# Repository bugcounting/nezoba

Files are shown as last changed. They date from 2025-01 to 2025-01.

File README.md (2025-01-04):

# Nez-Oba: a custom button-only game controller

The Nez-Oba[^1] project provides the schematics of a fully-programmable
all-button wired game controller board, as well as software to program
the controller's behavior to emulate a standard gamepad, and to
reconfigure its button layout.

The controller software works with Nintendo Switch (as a Pro
Controller), as well as with PC/Raspberry PI (as a generic USB
controller). While it can be used, in principle, for any game, it is
primarily intended to play 2D games that require precise button and
D-pad input &mdash; such as platformers.

## Why a custom controller?

Proficiency at 2D platforming games (Super Mario Maker 2, Celeste,
Super Meat Boy, Levelhead, Super Mario Bros. Wonder, Slime-san, Super
One More Jump, ...)  requires being able to precisely enter complex
button and directional inputs. A standard gamepad is not ideal for
this because:[^2]

- It usually has membrane button switches, which provide a suboptimal
  feedback and may not be as precise as mechanical switches.
  
- Its button layout requires to frequently move fingers (especially
  thumbs) from one button to the other. In contrast, an
  all-button/button-only/[hitbox style
  controller](https://ougaming.com/3/7198/a-quick-look-at-the-hitbox-vs-arcade-stick-de)
  minimizes hand and finger movement, and simplifies reliably entering
  complex presses.

There are numerous all-button controllers for PCs, and a few even work
with the Nintendo Switch. In particular, I like the [Junk Food
Arcades' Snack Box
Micro](https://junkfoodarcades.com/collections/snack-box-micro), as
well as [8bitdo's Arcade Stick](https://www.8bitdo.com/arcade-stick/)
[modded](https://www.youtube.com/watch?v=Yn7xL-vFdPc) with
[MyrzArcade's L-shaped
T-Spin](https://www.etsy.com/listing/733030620/t-spin-pcb-only-diy-tetromino-shaped)
(see also [OmniArcade's Odin](https://www.etsy.com/shop/OmniArcade) if
you like the WASD layout). The [Edgeguard keyboard
adapter](https://keyboard.gg/) also looks great. However, none of
these options supports switching between different programmable button
layouts without reconfiguring the board's software; their default
layout is not ideal for games like SMM2; and the distance between
buttons is somewhat wide, which can make repeatedly pressing certain
button combinations unconformable in the long run.

Hence, I went down this rabbit hole starting in the fall of 2021. The
first (and, so far, only) two fully working Nez-Oba game controllers
were completed in March 2022, and I've been using them with gusto ever
since.

After that, I worked on and off to improve the software, develop a
usable web-based GUI for definining the custom mappings, and to
provide detailed documentation. While there are still plenty of things
that could be improved, this is the first public release of the whole
project.[^3]

This is what the Nez-Oba game controller looks like IRL (this is the
version with black case and red linear Kahil low-profile switches):

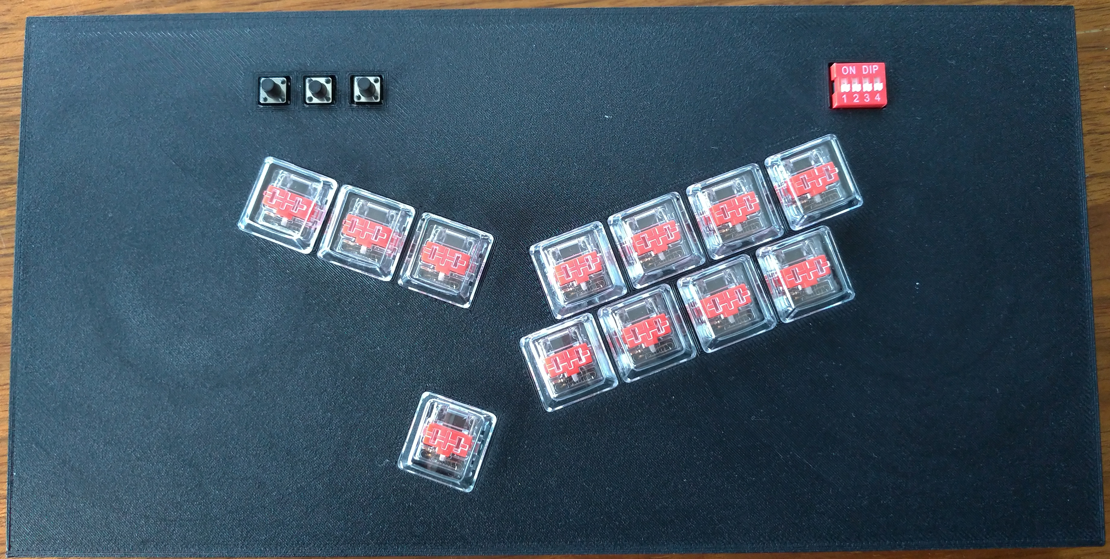
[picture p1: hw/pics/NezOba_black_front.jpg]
the Nez-Oba game controller in black


Its main features:

- Game controller board with twelve mechanical switches (as well as
  three auxiliary switches) and tight, comfortable physical layout.
  
- Fully remappable layout with capacity to store sixteen different
  button-to-key-press mappings.

- Each physical button can map to a combination of up to three
  simultaneous key presses.
  
- Support for turbo functionality (fast repeated key presses).

## Usage

The Nez-Oba projects includes both hardware and software components.

### Build the board

Under [hw/kicad/](/hw/kicad/) you will find:

- PCB schematics of the Nez-Oba board and how to manufacture them

- A list of components that have to be soldered onto the board

You will also need a USB-micro-to-USB-A cable to connect the board's
controller to the Switch or PC.

### Print the case

Under [hw/case/](/hw/case/) you will find 3D models of a case for
the game controller board, which you can 3D-print.

### Install the software

The Nez-Oba software is actually in two parts:

- An Arduino project in C/C++ with the software that runs on the
  board's microcontroller.
  
- A Python project to configure the button-to-key-press mappings that
  the on-board software supports.
  
The Python project is the single entry point to all software, since it
also provides commands to configure, compile, and upload the
microcontroller software.

You install this software as a regular Python project. As usual, it's
recommended that you create a virtual environment to install
dependencies more easily:

```sh
python3 -m venv venv
source vent/bin/activate
python3 -m pip install --upgrade pip
```

Then, there are different options to install the software:

1. Directly from GitHub:

```sh
python3 -m pip install git+https://github.com/bugcounting/nezoba
```

2. From a local copy the Git repository:

```sh
git clone https://github.com/bugcounting/nezoba
cd nezoba
python3 -m pip install .
```

3. From the release wheel:

Download
[/releases/latest/](latest
release wheel `nezoba*.whl`) and install it:

```sh
python3 -m pip install "$NEZOBA.whl"
```

You can also avoid downloading dependencies by using the
[/releases/latest/](`nezoba*.wheels.tgz`):

```sh
tar xf "$NEZOBA.wheels.tgz"
python3 -m pip install wheels/nezoba-*.whl --find-links=./wheels
```

### Use the software

Command `nezoba` is the entry point for using the whole
software. Start with `nezoba -h`.

A common workflow:

1. Have a look at the default button-to-key-presses mappings that I
   defined for 2d platformers: `nezoba show`.
   
2. If you want to define your own mappings, start the GUI with:
    `nezoba gui` (the GUI will appear at
    `http://127.0.0.1:8000/`). Alternatively, there's a simpler CLI
    shell that supports similar functionality: `nezoba cli $MAPPINGS_YAML`.
	
3. Setup the Arduino compiler and libraries with `nezoba setup
   "$SYSTEM_DIR"`, where `$SYSTEM_DIR` is the directory where you want
   to install them.
   
   Alternatively, among the [/releases/latest/](release files) you
   will also find an archive `arduino-cli-4nez.tar.xz` that includes a
   fully setup environment for Linux systems. Unpacking the content of
   that archive under `$SYSTEM_DIR` is an equivalent way of setting up
   your system.
   
4. Deploy the controller's software with your YAML mappings
   `$MAPPINGS`: `nezoba deploy "$SYSTEM_DIR" "$MAPPINGS"`. If you omit
   `$MAPPINGS`, the default mappings for 2d platformers will be
   deployed.
   
The `deploy` command will finally upload to the board. For this to
work, the board has to be plugged in to a USB port of the computer,
and it may have to be reset. See the [troubleshooting
section](/src/README.md#upload-troubleshooting) for a few practical
tips.
   
### Testing/development

If you want to test the installation of the Nez-Oba software, and
possibly change or extend its functionalities:

```sh
# Install the `test` target in editable mode
python3 -m pip install -e .[test]
# Run the Python tests
cd test/nezoba
pytest .
# Run the Arduino software tests
cd test/board
make test
./test
```

[^1]: What does the acronym "Nez-Oba" mean? I'm afraid I don't
    remember :-/

[^2]: Of course, top players make the most out of regular
    controller. On the other hand,
    [Niftski](https://en.wikipedia.org/wiki/Niftski), the
    [top](https://www.youtube.com/watch?v=i_9Hj--VfbY) Mario
    Bros. speedrunner at the time of writing, often uses a mechanical
    keyboard!

[^3]: The dev repository includes nearly 900 commits in 120 days over
    more than 3 years!

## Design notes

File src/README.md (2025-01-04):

# The Nez-Oba software

This directory contains all parts of the Nez-Oba software.

   - Directory [board/](/src/boards/) includes an Arduino project in
     C++, which is the program running on the board and emulates a
     gamepad. The `README` there outlines the code's structure and
     functionality.
	 
   - One of the libraries needed by the the Arduino project have to be
     patched to work with the used hardware. Directory [libs/](/src/libs/)
     includes patch a file to do so.
	 
   - Directory [data/](/src/data/) includes a sample mappings in YAML
     format. This includes several button-to-key-presses mappings that
     are useful to play 2D platformers on the Nintendo Switch or on a
     PC.
	 
   - Directory [nezoba](/src/nezoba/) includes the Python code
     implementing all of the functionality at the user's end,
     including a web-based GUI and a simple command-line interface to
     program the board. The `README`s there outline each package's
     functionality.
	 
   - Directories [src/remapper/](src/remapper/) and
     [test/remapper/](test/remapper/) include the Python
     implementation of a simple interactive shell and its tests. The
     shell can be used to define the button mappings that will be
     uploaded to the controller. See the `README` in those directories
     for details about how the shell is implemented and tested.
	 
   - The current directory's [nez-sw.py](nez-sw.py) is a Python script
     that can setup the Arduino compiler, install all dependencies,
     run the shell to define button mappings, and compile and deploy
     the controller software with the defined button mappings.
	 
The rest of this document describes some low-level details mainly
useful for future portability.

## Environment

This software has been developed and tested on a GNU/Linux Ubuntu
22.04 system. It should work without issues on any other Linux system,
and arguably also on other flavors of Unix. It should also be
adjustable to work on Windows systems without major hassle; however, I
didn't have a chance to test compatibility with that operating system,
and I will probably never care to do it.

## Portable Arduino frameworks
 
The [board's software](/src/board/) targets the Arduino ecosystem, and
was written using the [Arduino
IDE](https://www.arduino.cc/en/software). In order to compile and use
it, you also need to install the Arduino framework.

The main app `nezoba` takes care of installing the framework with all
dependencies under path `$SYSTEM_DIR`:
 
 ```sh
 nezoba setup "$SYSTEM_DIR"
 ```
 
The outcome of successfully running the `setup` command is the
command-line version of a [portable
IDE](https://www.arduino.cc/en/Guide/PortableIDE). This means that if
you save the keep the content of `$SYSTEM_DIR`, you can use it to
recompile and redeploy the controller software at any time in the
future, even after some of the dependencies are no longer available.
 
If you prefer to have the full Arduino IDE (for instance, to debug
changes of functionality in the software), [below I
describe](#portable-arduino-ide-with-dependencies) the manual steps to
do that. The `setup` command does exactly the same things but
automatically and using the CLI version of the Arduino framework;
therefore, the steps detailed below also serve as a documentation of
the behavior of the `setup` command.

In turn, these instructions are derived from the [NSGadget
project](https://github.com/gdsports/NSGadget_HID/tree/master/examples/NSGamepad),
which I found to be the one with the clearest and up-to-date
documentation among the several open-source projects that deal with
Nintendo Gamepad emulation. I adapted and updated the NSGadget's setup
to make it work with the MCP module and with my specific
configuration.

## Upload troubleshooting

When you `deploy` a mappings and the controller software onto a board,
the final upload step is often the most delicate. Here's how to deal
with common issues.

### Plug in the board

Make sure that the board is plugged in to a USB port before uploading.
You should see a port (usually, `/dev/ttyACM0`) pop up after the board
is connected.  There's no need to "activate" the board by pressing a
button.

### Port permissions

If you get an error `Opening port at 1200bps: Permission denied`, it
probably means that your user doesn't have access to the right groups
to access the port:

- Check whether groups `dialout` and `tty` are among the user's
  groups:

```sh
groups
```

- If they are not, add the user to the groups:

```sh
sudo usermod -a -G dialout,tty $USER
```

- This change of groups only works after the next login. To add the
  user to the groups right away:
  
```sh
newgrp tty
newgrp dialout
```

- If all else fails, you can try to change the permissions of the port:

```sh
sudo sudo chmod a+rw /dev/ttyACM0
```
### Resetting the board

After the first upload of the modified firmware, it should also no
longer be needed to reset the board to upload to it. Should you need
to reset the board, double-click on the reset button before launching
the upload. (The reset button is reachable from the little hole in the
back of Nez-Oba's case. After you reset, the led should [go from
purple to
green](https://learn.adafruit.com/adafruit-trinket-m0-circuitpython-arduino/circuitpython)).

## Portable Arduino IDE with dependencies

Here is the list of steps to setup a portable Arduino IDE with all
dependencies to compile and deploy the nez-oba controller software.

   1. Download the Arduino IDE for your computer as a zip file
      `arduino-ide.tar.xz`.
   
      - I used version
        [1.8.19](https://www.arduino.cc/en/Main/OldSoftwareReleases#previous)
        but more [recent versions](https://www.arduino.cc/en/software)
        should also work.
	   
      - The script installs [Arduino CLI
        0.21.0](https://github.com/arduino/arduino-cli/releases).
	   
   2. Install the IDE in portable mode to `$INSTALL_TO`, and launch it.
   
   ```bash
   tar xvf arduino-ide.tar.xz
   mv arduino-ide/ $INSTALL_TO
   cd $INSTALL_TO
   mkdir portable
   ./arduino
   ```
   
   3. Under **File -> Preferences**:

      - Uncheck **Check for updates on startup**
	  
	  - Add
        <https://adafruit.github.io/arduino-board-index/package_adafruit_index.json>
        to **Additional Board Manager URLs** (or follow other
        instructions from [Adafruit's
        documentation](https://learn.adafruit.com/adafruit-metro-m0-express-designed-for-circuitpython/arduino-ide-setup)).
		
   4. Under **Tools -> Board -> Boards Manager**:
   
      - Install **Arduino SAMD Boards** version 1.8.12 (more recent
        versions should still work).
		
	  - Install **Adafruit SAMD Boards** version 1.5.14 (more recent
        versions do not work with the `NSGadget_HID` library we'll use!).
		
   5. Restart the IDE.
   
   6. Download project https://github.com/NicoHood/HID version (tagged release) 
      2.8.3. This is the key library that performs controller
      emulation. This is a very actively maintained project (at the
      time of writing); more recent versions may work, but the patch
      that we'll apply has to be compatible with the changes.
	  
      - Download the project as zip file, and install it in Arduino
        IDE by selecting the zip under **Sketch -> Include Libraries ->
        Add .ZIP library**.
		
      - After installing, download the other project
        https://github.com/gdsports/NSGadget_HID commit
        `dfdcb35a07`. This is an extension of the HID project that
        supports emulation of Nintendo Switch gamepads. (The project
        also has an installation script with Arduino CLI, but here we
        simply get the files that we are going to use.) More recent
        versions may also work, but if the HID API undergoes breaking
        changes we may have to also refactor our controller software.
		
	  - Anyway, after downloading the `NSGadget_HID` project, copy the
        content of directories `src/SingleReport` and `src/HID-APIs`
        to the corresponding directories in the installed HID project
        (at `$INSTALL_TO/portable/sketchbook/libraries/HID/`). This
        should copy 4 files in total, 2 in each directory.
		
      - Edit file
        `$INSTALL_TO/portable/sketchbook/libraries/HID/src/HID-Project.h`
        by adding the following after `#include "SingleReport/SingleGamepad.h"`:
		
		```cpp
		#include "SingleReport/SingleNSGamepad.h"
		```
		
		Equivalently, patch it with file `libs/HID-Project.h.patch`. 
		This modification includes the `NSGadget_HID`'s extension headers 
		into the HID library.
		
   7. Edit the SAMD boards file
      `$INSTALL_TO/portable/packages/adafruit/hardware/samd/1.5.14/boards.txt`
      so that the uploaded image will use vid and pid numbers that
      are recognized as a Nintendo-compatible gamepad:
	  
      - Find the following two lines and comment them out with `#`:
	  
	  ```
	  adafruit_trinket_m0.build.vid=0x239A
      adafruit_trinket_m0.build.pid=0x801E
	  ```
	  
	  - Add the following two lines just below the commented out lines:
	  
	  ```
	  adafruit_trinket_m0.build.vid=0x0F0D
      adafruit_trinket_m0.build.pid=0x00C1
	  ```
	  
   8. That's it! Now the portable Arduino IDE has all the
      dependencies and options needed to compile and install the
      nez-oba controller software. Remember to switch to 
	  **Tools -> Board -> Adafruit SAMD -> Adafruit Trinket M0**
	  before compiling.

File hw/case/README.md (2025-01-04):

# The Nez-Oba game controller case

This directory includes CAD drawings of a case for the Nez-Oba
game controller board.

## 3D printing

The STL files can be sliced and 3D-printed. 

- `case-top-2.stl` and `case-bottom-2.stl` are the latest version of
  the case with wide top and bottom parts. The top part includes ten
  holes to host M3 threaded heat-set brass inserts, so that the bottom
  part can be screwed on to the top one. Once assembled, this case has
  a size of approximately 250x126x16 mm, which can be comfortably
  placed on your lap like a mini-keyboard.
  
- A previous design is available in two versions
  `case-{top,bottom}-wide.stl` and `case-{top,bottom}-narrow.stl`. The
  latter is only 207 mm wide, which means it is printable with most
  common consumer 3D printers (whose printable area is usually below
  210 mm). Another difference is that this variant hosts fewer
  heat-set inserts; as a result, the closed case might still show a
  little gap along the long edge; as a makeshift fix, you can print a
  few copies of `clip.stl` and use them to clamp onto the edge. The
  case remains fully usable, but it's not as nice as the other
  version.
  
Pictures `case_*.jpg` under [hw/pics](/hw/pics/) show the wider case
parts after 3D printing:

- The little hole in the bottom part allows you to reach the reset
  button of the Trinket microcontroller by simply using a pin, without
  having to unscrew the top.
  
- The solid ribs in the bottom part press onto the PCB to ensure that
  it does not move inside the case. They are not strictly needed, but
  they help get a tighter assembly.

I printed these in PETG material through
[Craftcloud](https://craftcloud3d.com/), a hub that dispatches 3D
print orders to providers in different countries.

## CAD sources

There are also fully editable Blender CAD sources (I created them with
Blender 3.6) of the two case design: `case-2.blend` is the latest,
wide design, whereas `case.blend` is the older design in two variants
(wide and narrow).

The overall model is built by combining various components using
Boolean modifiers (union and difference). If you want to modify any
parts of the model, you can find the various components hidden in the
list of objects.

Exporting the Blender model to `stl`format should give you the same
files as described in the [previous section](#3d-printing).

## 2D outlines

In this directory, you can also find other sketches I used to build
the 3D model of the case.

1. `footprints.svg` is a drawing exported from the [PCB
   schematics](/hw/kicad/) of the board, showing the footprints of the
   various components soldered onto the PCB. This is the starting
   point to figure out the design of the case.
   
2. `case-2.svg` is a vertical section of the case with dimension
   lines, showing the various holes and solids that make up the
   interior of the case. (As usual, `case.svg` is the slightly older
   design in two widths.)
   
3. `outlines-2.svg` takes `footprints.svg`, tweaks it, and adds the
   projections of the various elements that are present in the
   internal part of the case. (As usual, `outlines.svg` is the
   slightly older design in two widths.)
   
To create the Blender model, I imported `outlines-2.svg` and extruded
its bi-dimensional components to create three-dimensional shapes
following the dimension lines in `case-2.svg`.

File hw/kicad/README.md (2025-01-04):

# The Nez-Oba controller board

This directory schematics and assembly instructions for the Nez-Oba
game controller board, which can be manufactured as a PCB and then
programmed using the software available [elsewhere](/src/) in this
repository.

The board's design is defined in a [KiCad](https://www.kicad.org/)
(version 5.1.5) project including a schematics, a PCB layout, and
symbol and footprint libraries to make the project self-contained.

## Components

The PCB mounts the following components:

   - An Adafruit [Trinket M0](https://www.adafruit.com/product/3500)
     development board, which runs the controller software.
	 
   - An MCP 23017 port expander, which communicates with the Trinket
     through a clocked serial line. The expander supports 16
     independent digital inputs, which are needed for the many
     buttons of the controller.
	 
   - A piano-type 4-bit DIP switch, which stores the controller's
     configuration number (which, in turn, determines the mapping of
     buttons to gamepad keys).
	 
   - 12 mechanical switches, meant for the 4 directional inputs and 8
     main gamepad buttons.
	 
   - Another 3 switches, meant for the 3 auxiliary gamepad buttons
     (such as *select* and *start*).
	 
The switches are in two groups because the board uses mechanical
switches for the main buttons, and smaller/cheaper tactile buttons for
the auxiliary buttons. However, they all behave the same (and one
could easily change switch type without having to change the
schematics).

## Schematics
	 
The 15 switches are connected each to a separate input of the
expander.  The mapping switch-to-expander makes it easier to lay out
the tracks in the PCB. However, it's essentially immaterial, since any
remapping can be defined via software.

The 4 pins of the DIP switch are connected to the remaining available
digital inputs: 3 of them connect to pins 1, 4, and 2 of the Trinket;
the last one connects to the last input of the expander.

The rest of the connections complete the schematics:

   - All ground pins connect to the Trinket's `GND` pin, which is
     connected to the USB power's ground (hence, it's an output pin
     for the circuit).
	 
   - The expander's three address pins `A0`, `A1`, and `A2` also
     connect to ground. This corresponds to using the [default
     address](https://www.best-microcontroller-projects.com/mcp23017.html)
     0x20. Adding other I2C devices may require to change the address,
     by setting some of these pins to high.
	 
   - The expander's `VDD` and `RESET` pins connect to the Trinket's
     `USB` pin, which draws 5V from the USB power (hence, it's an
     output pin for the circuit).
	 
   - The expander's clock (`SCL`) and data (`SDA`) pins connect to the
     Trinket's clock (pin 2) and data (pin 0) pins (see the [Trinket's
     pinout](https://learn.adafruit.com/adafruit-trinket-m0-circuitpython-arduino/pinouts)). They
     also connect to 5V each [through
     a](https://learn.adafruit.com/using-mcp23008-mcp23017-with-circuitpython/python-circuitpython)
     4.7k Ohm pullup resistor.

## PCB

The symbols used in the schematics are associated with footprints
suitable for the different components used on the PCB. The symbols
also include information about exact product numbers and
manufacturers, so that it should be possible to generate a BOM (bill
of materials) for automated assembly.

The expander has a footprint for a standard DIP packaging with 28 pins
at 2.54mm-pitch, with a form factor of 36x7.8mm.

The 12 mechanical switches mount [Kailh
Choc](https://www.kailhswitch.com/news/kailh-low-profile-mechanical-switches-series-19669171.html)
low-profile mechanical switches. The pin layout is incompatible with
the more common Cherry MX buttons (or other kinds of high-profile
buttons). However, the footprint's size is the same; hence, it should
not be hard to change the design to accommodate Cherry MX switches.

There are *two* symbols for Kailh switches, one for the red (linear)
switches and one for the white (clicky) ones. They are physically and
functionally identical; I created two symbols only to have a way of
storing manufacturer information for both kinds of switches. Indeed,
you can use any other kind of Kailhs, provided they are low profile.

The 3 auxiliary switches mount the cheap 4-pin tactile button
switches, which are very common in cheap electronics starter kits. The
pair of pins on each side of the switch are connected to each other;
clicking the switch connects the pairs on opposing sides. To make this
clear, the PCB connects the two holes on one side of the footprint
with a track. When soldering the switches, make sure to test which
side is connected!

The front layer mounts all switches: main buttons, auxiliary buttons,
and DIP configuration switch. The back layer mounts the control
electronics: Trinket, expander, and the two pullup resistors. This
layout minimizes the height of the top layer, so that the box can
touch the top layer's surface almost everywhere in a stable way.

Most wiring runs on the bottom layer, with only a few short tracks on
the top layer. Filled zones on the top and bottom layers are connected
to ground, which makes for a simple wiring of all ground pins.

The PCB also includes four 4.5 mm diameter mounting holes, at the four
corners of the board.

### Variants of the expander component

A previous version of the controller board (0.1, which was just a
prototype) used an expander mounted on a terminal breakout board
(usually called an CJMCU 2317). This component has the same pinout
(and behavior) as the MCP 23017 expander, but is wired [slightly
differently](https://www.best-microcontroller-projects.com/mcp23017.html):

   - The expander's clock and data pins do not use pullup resistors:
     they just connect to the Trinket.
	 
   - The expander's `RESET` pin connects to 5V through a 10k Ohm
     resistor.

In the attached library, there are also footprints for two models of
terminal breakout boards (of different widths), which should be
mounted using pin headers. The default, however, is to use the MCP
23017 expander without terminal breakout board.

## Changing the board's layout

If you change anything in the schematics (or PCB):

  1. Run the ERC (Electrical Rules Checks) in the schematics layout
     editor (ladybug icon), to make sure they all pass.
 
  2. In the PCB layout editor, click on *Update PCB from schematic*
     (icon to the left of the ladybug icon)
     
	 - Uncheck *Delete extra footprints*, so that the mounting holes
       are not removed.
	   
     - If you didn't change any references (for example, by changing
       it in the footprint editor) you can select *Re-associate
       footprints by reference*. Note that the footprints in library
       `nez-footprint` are set up so that they do not display the
       reference in the PCB view; instead, they display extra text
       that you can customize to reflect the function of each
       component (e.g., each button's default behavior).
	   
     - Click on *Update PCB* and make sure there are no errors.
	   
  3. If you changed anything in the footprints, select *Tools ->
     Update Footprints from Library*. After clicking on *Apply* there
     should be no errors.
	 
  4. Run the DRC (Design Rules Checks) in the PCB layout
     editor (ladybug icon), to make sure they all pass.
	 
	 - Check *Refill all zones*.
	 
	 - I recommend to check both *Report all errors* and *Test tracks
       against filled copper* to perform all checks. It won't take
       long on this simple PCB.
	   
     - Click on *Run DRC* and make sure there are no errors.

In the PCB layout editor, layer *Dwgs.User* is hidden by default. This
includes outlines of all components, which are useful to re-place
footprints after some significant component change.

## Ordering components

The components' symbols also include a link to a page in Digi-Key's
online catalog.

More directly, here are some suggestions about where to buy the
components (from mostly European distributors, but it should not be
hard to find them elsewhere):

   - Any basic 4.7k Ohm resistor should be fine. 5k Ohm ones should
     also work (although I haven't extensively tested them).

   - The 3 auxiliary switches are very common components. Make sure
     you select some with a sufficiently long button cap, so that it
     reaches out of the case.
	 
   - The 4-bit DIP switch is also very common. Check that its
     footprint fits the enclosing case's hole; height should not be an
     issue.
	 
   - Suppliers of components for mechanical keyboards should have the
     Kailh switches, although the Choc models are a bit less widely
     available. (I bought mine from
     [MyKeyboard](https://mykeyboard.eu/): EUR 11 for 20 switches; but
     this seller is [no longer in
     business](https://www.reddit.com/r/MechanicalKeyboards/comments/1ctgniw/mykeyboard_eu_is_bankrupt/). Alternatively,
     there's [42.keebs](https://42keebs.eu/) which is also EU based.)
	 
   - For the expander, look for MCP23017-E/SP components; "E/SP"
     denotes the packaging that the controller uses. As discussed
     [above](#variants-of-the-expander-component), with the default
     layout you just need the bare component, without any mounting
     socket or terminal breakout board (although adding a socket to
     the design should not be hard). Any online electronics shop
     should have them. (I bought mine on Amazon: EUR 4.)
	 
   - Finally, the Trinket M0 should also not be too hard to find. (I
     bought one of mine on Amazon; another one from
     [Distrelec](https://www.distrelec.ch/), which has online stores
     in various countries: CHF 10.)
	 
Altogether, the bare components should cost around EUR 30 (although
you may have to buy some in bulk, using only a few of them).

## PCB manufacturing

To send the PCB layout for manufacturing you can usually either send
the `.kicad-pcb` file or generate plot and drill files. I'll describe
this second way, which is more widely supported (although most PCB
manufacturers also accept CAD files nowadays).

   1. In KiCad's PCB layout editor, click on *Plot* (plotter icon,
      right of the printer icon).
	  
      - *Plot format*: Gerber
	  
	  - Select the following layers: F.Cu, B.Cu (front and back
        copper), F.SilkS, B.SilkS (front and back silk screen),
        F.Mask, B.Mask (front and back solder masks), and Edge.Cuts
        (the perimeter of the board). 
		
	  - Click on *Plot*. This will generate 7 plot files with
        extension `.gbr` (one per layer).
		
	  - In the same window, click on *Generate Drill Files*, and then
        again *Generate Drill File* in the window that opens. This
        will generate 2 drill files with extension `.drl`: one for
        plated through holes (PTH) and one for non-plated through
        holes (NPTH).
	  	
   2. Create a zip file including all 9 generated files (plot and
      drill files).
	   
   3. On the manufacturer's main page, you usually start by an
      approximate size for the PCB. You can measure it in the PCB
      layout editor with the measure distance tool (calipers icon):
      180x104mm should work for the controller board.
	   
   4. Then you upload the zip file with all plot information, and
      select any other options for manufacturing. Default options
      should be fine for this project.
	   
   5. The manufacturer will then perform additional checks to confirm
      they can manufacture the PCB.

I used [EuroCircuits](https://www.eurocircuits.com/) to manufacture my
two Nez-Oba PCBs. They have reasonable prices and deliver high-quality
boards (but YMMV, of course). I payed around EUR 70 for one PCB,
including shipping costs.

## Soldering components

When you assemble the PCB by soldering the components on it, there are
a few things to pay attention to.

   - The Kailh switches' mounting holes are asymmetric, so there's
     only one way that the switches will fit them.
	 
   - The DIP 4-bit switch can be mounted in either directions, but I
     recommend to mount it so that any text on the PCB (especially the
     bit numbers) is readable in the board's "natural" orientation,
     which is the one where the large writing *NEZ-oba* is readable.
	 
   - As explained above, the 4-pin auxiliary button switches have a
     polarity. Check with a multimeter which pairs of pins are wired
     to each other, and then insert one such pair into the pair of
     mounting holes that are also wired with a track on the top layer
     (red line in the PCB layout editor).
	 
   - The MCP23017 also has a polarity. Its [pin
     #1](https://ww1.microchip.com/downloads/en/devicedoc/20001952c.pdf)
     should be marked with a little dot on the DIP packaging; that pin
     goes into the bottom right mounting hole on the back of the PCB,
     which is also marked with a square pad (instead of circular as
     all other mounting holes), as well as with the writing *B0*.
	 
   - Solder header pins to the Trinket, and then solder the other end
     of the pins onto the bottom of the board. Use the writings on the
     board to properly orient the Trinket. In a nutshell, the
     Trinket's top layer (where the tiny reset button is) should face
     away from the PCB's bottom layer, in a way that the Trinket's
     micro USB port is next to the PCB's top edge.
	 
 If you're not sure, use a breadboard to test the components with the
 software, and then assemble them.

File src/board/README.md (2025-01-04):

# The Nez-Oba gamepad controller board's software

This document overviews the structure and logic of the Arduino gamepad
controller board's software, which is included in this directory.

## Configuration numbers

First, a reminder of how users of the board specify which
button-to-key-presses mapping should be used.

The game controller board includes a 4-bit switch in the top-right
corner. The positions of the four microswitches determine the
controller's *configuration number*; each configuration number
corresponds to a different button-to-key-presses mapping.

Thus, a configuration number is an integer in the range from 0 to 15
(included); thus, the controller stores up to 16 different button
mappings.  To select configuration number `N`, move the microswitches
so that they spell out `N` as a four-digit binary number: a
microswitch in the upper position indicates binary digit `1`, and a
microswitch in the lower indicates binary digit `0`. For example,
configuration number `5` (`0101` in binary) is selected when the first
and third microswitches are low, and the second and fourth
microswitches are high.

If you use the Nez-Oba GUI, it wil display the configuration number as
it should appear on the board.

## Main file: `board.ino`

The entry point of the board software is Arduino project file
`board.ino`.  The program is not that long, but it's broken down into
several included files so that it's easier to navigate and modify, and
so that it can be more easily tested.

By default, the `#define DEBUG` definition is commented out, so that
the software is ready for deployment. If you uncomment it, when the
program runs on the board it will print what it's doing in each step
on the `Serial` interface. You can use this to check the buttons
before actually connecting the board to the host. (Printing on
`Serial` doesn't interfere with the controller's functionality, so you
can also use a debug build on the host.)

## File `debug.h`

File `debug.h` is included next.  This defines the macro `debug()`,
which prints its argument on `Serial` (if `TESTING` is not defined) or
on standard output. The offline testing program (in directory `test`)
defines `TESTING` to use the latter; the standard debugging behavior
uses `Serial` as described above.

Macro `debug()` is always defined, instead of being removed by the
preprocessor if `DEBUG` is not defined. This has the advantage of
ensuring that the debugging code remains consistent with the deployed
code (or at least that it can be compiled). Then, we rely on the
optimizing compiler to remove the `debug()` statements (which are
never executed when `DEBUG` is undefined).  This is the reason why
`debug()` is written as a `do ... while` loop: it should make it
easier for the compiler to recognize it as dead code. Indeed, you can
check that the compiled program size in non-debug mode remains the
same, even if we define macro `debug()` as empty.

The other macros `init_time()` and `loop_end()` implement basic
measures of performance. Macro `init_time()` should be called at the
end of the controller's setup to save the absolute time then. Macro
`loop_end()` should be called at the end of each iteration of the main
control loop; it will update and print the average time it took to
complete a control loop.

These macros are meant for online testing (`DEBUG` defined but
`TESTING` undefined); however, they work also during offline testing
to check that they do not interfere with the rest of the control
program.

## File `keys.h`

File `keys.h` defines several constants that identify the various
buttons and keys of the controller.

A **button** is a physical button on the nez-oba.
There are `N_BUTTONS` such buttons, each identified by an integer in the 
range `[0..N_BUTTONS-1]`.

The comment above the definition of `N_BUTTONS` shows how the buttons
are to be numbered in any mapping. It's important that function
`nezoba.remapper.encoding.Exporter.encode` encodes buttons in the same
order. If you need to change this order, you'll have to adjust the
definition of `BUTTONS2CMP` in `globals.h` consistently.

A **key** is an event that can be triggered on the emulated gamepad
(a key press);
there are `N_KEYS` such events in total, 
each identified by an `enum` integer in the range `[0..N_KEYS-1]`.
There are several categories of keys, identified by macro predicates.

- Keys `n` that satisfy `IS_NOOP(n)` correspond to a "no op", used to
  map controller buttons that are disabled.
	 
- Keys `b` that satisfy `IS_BUTTON(b)` correspond to regular gamepad
  buttons, that is everything other than a directional input.
	 
- Keys `d` that satisfy `IS_DP(d)` correspond to 9 D-pad directions:
  up, up right, right, down right, down, down left, left, up left, and
  centered (neutral).
	 
- Keys `l` that satisfy `IS_LS(l)` correspond to 9 left-stick
  directions (the same as the D-pad).

- Keys `r` that satisfy `IS_RS(r)` correspond to 9 right-stick
  directions (the same as the D-pad).
	 
A **mapping** associates each button to up to three keys.
The *current* mapping is stored in three arrays `KEY1`, `KEY2`, and `KEY3`:
`KEY1[b]`, `KEY2[b]`, and `KEY3[b]` are the three key events that
are triggered (simultaneously) when button `b` is pressed.

In most cases, you only want to trigger one key event per
button. Then, just set one mapping slot to the key event, and the
other two slots to `K_NOOP`.

If you want to **turbo** a key event `K`, set the mapping to `-k`.
Turboing a key means that the controller will rapidly toggle pressing
`K` with a small delay. Turbo is only applicable to regular buttons,
not to directional inputs.

Multi-dimensional array `MAPPINGS` combines 16 `3 * N_BUTTONS`-element
arrays, one for each of the 16 remappings that the controller software
supports.  File `remapNN.h` stores remapping number `NN` (numbered
from `00`) as an initializer of a `3 * N_BUTTONS` array, whose
elements are the remapping's key values in the same order as the
button numbering.  Therefore, the elements at indexes `3*b`, `3*b + 1`, 
and `3*b + 2` are the three keys mapped to button `b`. Again,
`nezoba.remapper.encoding.Exporter.encode` produces an encoding 
consistent with this format.

To change a mapping directly, edit the corresponding `remapNN.h`
maintaining this structure. Use `K_NOOP` for each remapping slot that
you don't want to use. In most cases, though, you won't need to edit
these files directly. If you do, though, command `nezoba decode` can
translate the files `remapNN.h` back into an instance of `Mappings`
used by the Python software.

## File `mcp.h`

File `mcp.h` introduces several macros useful to access the MCP unit
using the I2C protocol through library `Wire`. 

An earlier prototype of the nez-oba software used instead (an older
version of) [Adafruit's MCP23017 Arduino
library](https://github.com/adafruit/Adafruit-MCP23017-Arduino-Library)
together with a [debouncing library for
MCPs](https://github.com/cosmikwolf/Bounce2mcp). However, this just
introduced a significant overhead and, worse, a dependency on older
libraries. By rewriting everything using library `Wire` directly, the
current software is faster, simpler (and hence easier to modify) and
with minimal dependencies on legacy software.

An MCP 23017's 16 input/output pins are split into two banks `A` and
`B` of 8 pins each. Therefore, several registers are split into two
byte-size registers, one for each bank `A` and `B`; the 8 bits of a
byte define the state of the 8 pins in a each bank.

Initially, the file defines several register addresses:

- `MCP_ADDRESS` is the MCP's address on the I2C serial bus, when pins
  `A0`, `A1`, and `A2` of the MCP are all connected to ground. When
  using multiple MCP cascading units, one would change this address by
  setting some of those pins to a high value.

- `MCP_IODIRA` and `MCP_IODIRB` are the addresses of the registers
  used to configure the pins as input (value 1) or output (value 0).
	 
- `MCP_GPPUA` and `MCP_GPPUB` are the addresses of the registers use
  to enable the pull-up resistors (value 1) of any input pins.
	 
- `MCP_GPIOA` and `MCP_GPIOB` are the addresses of the registers that
  store the value (low 0, or high 1) of the pins (or set the value for
  pins configured as output).
	 
- `MCP_GPINTENA` and `MCP_GPINTENB` are used to turn on (value 1) or
  off (value 0) interrupt triggers for each pin.
	 
The MCP module has several other registers for functionality that the
nez-oba doesn't use. All addresses are from [version 1.3.0 of
Adafruit's MCP
library](https://github.com/adafruit/Adafruit-MCP23017-Arduino-Library/blob/1.3.0/Adafruit_MCP23017.h),
which was used in an older version of the controller board software. I
found some register addresses used in
[other](http://www.learningaboutelectronics.com/Articles/Read-input-from-an-MCP230xx-IO-port-expander-connected-to-an-arduino.php)
[MCP
guides](http://www.learningaboutelectronics.com/Articles/MCP23017-IO-port-expander-circuit-with-arduino.php)
not to work with the MCP units I have experimented with. If you find
issues with yours, you may want to check the MCP's spec sheet.

Another point to notice is that the nez-oba software still adopts the
pin ids used by Adafruit's MCP23017 library:

| Pin Name | MCP23017 Pin # | Pin ID |
|:---:|:---:|:---:|
| GPA0 | 21 |  0 |
| GPA1 | 22 |  1 |
| GPA2 | 23 |  2 |
| GPA3 | 24 |  3 |
| GPA4 | 25 |  4 |
| GPA5 | 26 |  5 |
| GPA6 | 27 |  6 |
| GPA7 | 28 |  7 |
| GPB0 |  1 |  8 |
| GPB1 |  2 |  9 |
| GPB2 |  3 | 10 |
| GPB3 |  4 | 11 |
| GPB4 |  5 | 12 |
| GPB5 |  6 | 13 |
| GPB6 |  7 | 14 |
| GPB7 |  8 | 15 |

This is really just a legacy of the earlier version of the software,
but switching to a different scheme has no real advantages, and the
number scheme is anyway immaterial.

The following macros in `mcp.h` assume this numbering
scheme. 

- `IS_GPIOA_PIN` and `IS_GPIOB_PIN` determine if their argument is the
  id of a pin in bank `A` or `B`.
	 
- `PIN2REGISTER` evaluates to `MCP_GPIOA` or `MCP_GPIOB` according to
  whether its argument is the id of a pin in bank `A` or `B`.
	 
- `PIN2BITMASK` gives an 8-bit bitmask where all bits are 0 except for
  the one corresponding to the argument pin id (which is set to
  1). For example, `PIN2BITMASK(14)` is `01000000` (`64` in base 10),
  where the 7th bit from the right is `1` since 14 is the id of pin #7
  in bank `B`.
	 
Macro `MCP_WRITE` takes a register address `REGISTER` and a byte-size
`VALUE`, and writes `VALUE` to `REGISTER` using the I2C protocol: it
initiates the transmission, it sends the `REGISTER` address, it sends
the `VALUE` to be written on that register, and it terminates the
transmission.
 
Macro `MCP_READ` takes a register address `REGISTER` and reads a byte
from that register using the I2C protocol: it initiates the
transmission, it sends the `REGISTER` address to be read, it
terminates the transmission, and it sends a request of 1 byte (from
the register that was just selected). After these statements,
executing `Wire.read()` returns the byte read from the MCP unit.

## File `globals.h`

File `globals.h` defines global variables used by the control
software, and includes the necessary libraries.

Constant `TURBO_PERIOD` defines the delay (in milliseconds) between
toggling a button that is turboed. Then `TT` is just a boolean flag
that is toggled every `TURBO_PERIOD` milliseconds; its boolean value
determines if a pressed turboed button should be pressed on the host.
Currently, only a value of turbo period can be selected, corresponding
to 75 Herz. Any different turbo frequency will be treated as 75 Hz by
`nezoba encode`.

Array `BUTTONS2MCP` translates each button number into the id of the
corresponding MCP unit's pin the physical button is attached to. As
mentioned above, pin ids are as in Adafruit's MCP23017 library. The
names in comments correspond to the names that are printed on the PCB
for identification (although they can obviously be remapped to any key
presses). Remember that the order of elements in this array must be
consistent with the button ordering in the `remapNN.h` files.

Constant `DEBOUNCING` defines the debouncing time (in milliseconds).
Constants `P_CFG_N` define the pin number of the four configuration
bits that are defined on the DIP switch. The first three of them are
bits on the Trinket board; the fourth one is a pin on the MCP (just
because there were no more pins available on the Trinket).

Variable `CFG` will store the current configuration number, as an
integer between 0 and 15.

Then all needed libraries are imported. The `#include` are
conditional: when `TESTING` is set (which is used by offline testing),
some library stubs are imported instead.

Several variables of `byte` type (8 bits) are used for communications
with the MCP unit. Variables `GPIOA_state` and `GPIOA_previous` store
the current and previous state of the `A` pins in each iteration of
the control loop. Variables `GPIOB_state` and `GPIOA_previous` serve
the same purpose for the `B` pins.

Finally, `GPIOA_last_debounce_time` and `GPIOB_last_debounce_time`
record the absolute time (in milliseconds since when the controller
was turned on) when the `A` or `B` pins' state was *debounced*, as
we'll describe later. Using `unsigned long` as type ensures that
debouncing can work for up to more than 49 days of continuous
operation. After that, you may have to unplug and plug back in the
controller if it malfunctions :-)

Array `KEYS2PAD` maps each key to a corresponding named constant in
the `NSGamepad` API. Some of these named constants are the same
number, but it doesn't matter since they are supplied to different
methods of the API (in particular, regular buttonsvs D-pad
directions). At the moment, analog sticks are not supported, and hence
there is no mapping of the corresponding keys to analog stick
directions. Adding support for them should not be hard, but I didn't
implement it since I wouldn't be really using it. I may do so in the
future!

## File `setup.h`

File `setup.h` contains the body of Arduino's `setup()` function,
which is executed once when the board boots up.

The setup performs the following steps:

1. It starts the `Wire` library used to access the MCP unit.

2. It sets the four pins reading the four configuration bits (three on
   the Trinket and one on the MCP module) to *input* with *pullup*
   resistor.

3. It reads the four configuration bits, converts them to an integer
   configuration number `CFG`. The configuration first bit is the most
   significant one.
	  
4. Based on the value of `CFG`, it copies the corresponding mapping
   for each button into arrays `KEY1`, `KEY2`, and `KEY3`.
	  
5. It sets `N_BUTTONS` MCP pins to *input* with *pullup* resistor,
   creates a debouncer object for each of them, and stores the objects
   in array `BUTTONS`.
	  
6. It starts the gamepad module.

7. It records the current time at the end of setup (macro
   `init_time()`).

Since this setup is done only once the board is booted up, if you
change the configuration number you have to turn off and on again the
board for it to take effect.

## File `key_handler.h`

File `key_handler.h` contains the definition of macro `HANDLE_KEY()`,
which decodes a button press into presses or directional inputs on the
gamepad. This macro is used in each iteration of the main control loop
described below.

Macro `HANDLE_KEY`'s argument `KEYID` identifies one of the three
remapping arrays `KEY1`, `KEY2`, and `KEY3`. The other argument `B`
identifies the currently pressed button.

The macro first reads the key that `B` maps to in remapping `KEYID`,
and stores the key value into fresh variable `_k`.  If `_k` is negative, it
means that it corresponds to key `-_k` with turbo.  If this is the
case, it sets the `turboed` and `add_turbo_delay` flags, and changes
the sign of `_k` so that it correspond to a valid key.

If key `_k` is a regular button (not a directional input), the macro
presses it on the gamepad by calling function `press()` after
translating `_k` to the corresponding constant in the `NSGamepad` API.

The condition for calling `press()` is also that `!turboed || TT`:

- If `turboed` is false, the button is just pressed.
   
- If `turboed` is true, the button is pressed only in every other
  control loop cycle, as determined by the turbo-toggle flag `TT`.
	 
If key `_k` is a directional input, the macro combines this
directional inputs with the others into variables `dpad_x` and
`dpad_y`. These variables are initialized to `0` in each iteration of
the control loop. Each directional input changes these variables:
right and left correspond to `+1` and `-1` on `dpad_x` respectively;
up and down correspond to `+1` and `-1` on `dpad_y` respectively.

After reading all directional inputs, we want `dpad_x` and `dpad_y` to
be in the integer range `[-1..+1]`. To this end, macro `HANDLE_KEY`
also resets their values if they have exceeded this range. For
example, it may happen that two buttons are both associated with the
same direction *right*. Then, `dpad_x` would be set to `2`, and then
reset to `1` (which unambiguously identifies a right direction).

This logic also performs some basic SOCD cleaning. SOCD (Simultaneous
Opposite Cardinal Directions) is a problem that occurs when two
directional buttons corresponding to incompatible directions are
pressed simultaneously. For example, pressing *left* and *right*
cannot result in a valid directional input. The gamepad's API that we
are using requires a single 8-direction input for the D-pad, so we
have to resolve these possible inconsistencies. Even if the API
allowed SOCD input, it would still be advisable to avoid it, since it
may lead to inconsistent (possibly nondeterministic) behavior in
games. By using coordinates `dpad_x` and `dpad_y`, opposing
directional inputs reset the corresponding direction to `0` (center),
thus taking care of resolving inconsistencies.

## File `main_loop.h`

File `main_loop.h` contains the body of Arduino's `loop()` function,
which is executed in an infinite control loop.

Each iteration of the control loop performs the following steps:

1. It releases all gamepad keys.

2. It complements the turbo-toggle flag `TT`.

3. It goes through all buttons, and checks which have been
   pressed. For each pressed button, it executes macro `HANDLE_KEY`
   for each of the three keys mapped to the button.
	  
4. It sets a D-pad direction based on the horizontal and vertical
   coordinates `dpad_x` and `dpad_y`.
	  
5. If a key was turboed, it adds a delay.

6. It commits all presses to the gamepad module.

7. It computes and displays the average time to complete a loop
   iteration (macro `loop_end()`).

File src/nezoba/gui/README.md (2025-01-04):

# Package `nezoba.gui`

Package `nezoba.gui` offers an implementation of a web-based GUI,
which supports visual inspection and editing of button-to-key-presses
mappings (defined in package `nezoba.remapper`).

The implementation uses the JustPy web framework. In the end, I had to
extend several components and features of the framework to fit my
needs. Most important, I modified the `justpy.Svg` component to be
able to use parts of an SVG image as clickable and dynamically
editable GUI buttons. Since I didn't want to distribute my own fork of
JustPy, I ended up doing some fairly heavy monkey patching, mostly in
module `utils` described below.

## Module `gui`

This module sets up the GUI as `justpy.WebPage`. The GUI's layout
includes several panes, each either a regular `Div` or a specialized
component defined in module `panes`.

The main wepage uses a [favicon](imgs/nez-oba-favicon.ico), which can
be generated from [this SVG](imgs/nez-oba-favicon.svg) using an
[online converter](https://favicon.io/favicon-converter/).

## Module `panes`

This module includes several specialized HTML components used by the
GUI:

- `Header` is the page's header banner, with the name and number of
  the current mapping.
  
- `Controller` is the page's left main pane, which displays a stylized
  image of the Nez-Oba controller board, whose buttons can be clicked
  to associate a key press with each of them.
  
- `PressList` is used in the page's right main pane, which displays
  all the presses associated with the currently selected button. Each
  press is displayed as an instance of `PressBox`, which shows all the
  information about the press (e.g., if it's turboed) and allows the
  user to edit it.
  
- `Info` is the page's left bottom pane, which shows a description and
  the platform used by the currently displayed mapping.
  
- `Menu` is the page's right bottom pane, with buttons to load/save
  the mappings, create a new mapping, switch between mappings, and so
  on. 

As noted elsewhere, sometimes this module's documentation refers to a
mapping (e.g., the currently selected mapping) as a *configuration*
(e.g., the current configuration). A configuration is often associated
with its index (*configuration number*) in the list of mappings in the
menu.

## Module `widgets`

This module includes other HTML components, which are used as building
blocks by some of the `panes`.

- `OnOffComponent` and `HideShowComponent` are SVG components that can
  be displayed or hidden dynamically.
  
- `InOutButton` is an SVG component that can display text on it (this
  is the *out* part), can be activated by clicking on it and
  deactivated by clicking again (this is the *in* part).
  
- `HoverHighlight` is a way of explicitly highlighting an SVG
  component's background when the mouse hover over it.
  
- `LabelContent` is a `div` component organized as vertically stacked
  subcomponents, each consisting of a label and some content.
  
- `ButtonRange` is a `div` component that displays a range of buttons.

- `SelectOptions` is a `select` component that reacts to changes in the
  model.
  
- `NamedLink` is an `a` link component that displays the URL in the
  model.
  
- `IconButton` is an HTML button component that displays text and/or
  icons on its face.

## Modules `model` and `views`

One of the main overhauls of JustPy is its support for model-based
dynamic components. In JustPy, a component's model is a way of
associating the component's state to the dynamic value of an attribute
(called the *model* of the component). In JustPy, the model[^1] is usually
of type string or integer. In the Nez-Oba GUI, this capability is
substantially extended to accommodate complex model types.

Class `State` encapsulates all the information that characterizes the
GUI's overall state: all mappings, the currently selected mapping, any
save files, and so on.

A component does not directly access the whole state. Instead, a
different `View` encapsulates the whole state and only leaks
information that is needed for a particular purpose. Precisely, `View`
has a single public member `value`, implemented as a property, which
can be read and, possibly, written (depending on whether the component
accessing that view is allowed to change the state).

JustPy's components are equipped with methods `get_model` and
`set_model` to respectively read and write the current model value
linked to that component. Module `model` redefines these methods in a
way that they work on views by default. 

Module `views` includes the actual subclasses of `View` that are used
by GUI components.

## Module `utils`

This module is where most of the dirty work of adapting JustPy's
functionality to our needs is done. Here, I will just describe the
main functions.

- `instrument_component_class` equips an existing JustPy component
  class with all of the extra functionality implemented in this
  project. In particular, it replaces the original `get_model` and
  `set_model` with their extensions defined in `model`.
  
- `filter_by_attribute` provides a way of searching through the
  subcomponents of an HTML component (usually, an SVG) for elements
  with certain attribute values. This is mainly used to display and
  dynamically modify the SVG of the Nez-Oba game controller board as a
  collection of clickable GUI buttons.
  
- Similarly, `by_layer_spec` navigates an SVG not by attribute values
  but according to its hierarchical tree structure. Other functions
  used this in combinatino with `replace`, which supports
  modifications of some parts of a tree structure.
  
- `add_styles` provides a more flexible way of adding CSS styles or
  Tailwind classes to an HTML component in JustPy. This function is
  needed because the version of JustPy that was available when I
  developed Nez-Oba only had support for older versions of Tailwind;
  hence, I had to manually implement some style changes that would
  have been possible with more recent version of Tailwind.
  
- `pack_text` resizes multiple lines of text so that they can be
  displayed to fit (more or less) nicely a bounding box.

- `wrap` provides another kind of monkey patching, one that is used
  directly in the definition of some panes. Precisely, it can turn an
  SVG component into an instance of `InOutButton` or `OnOffComponent`.

[^1]: Pet peeve: JustPy documentation's and terminology occasionally
    uses "model" to refer indifferently to the model *value* (the
    current value of the component's state) and to the *model type*
    (the range of values that the component's state spans). I tried to
    be more rigorous with the terminology, but no takesies-backsies
    :-).

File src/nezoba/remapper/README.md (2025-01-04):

# Package `nezoba.remapper`

Package `nezoba.remapper` provides the main abstractions to define
button-to-key-presses mappings. They are deliberately more general
than what is strictly supported by the Nez-Oba controller board's
software at the moment, so that they may be usable also with future
extensions of the hardware and its software.

## Buttons: module `buttons`

A `Button` instance represents a physical button on the game
controller that can be pressed or depressed. Each button is uniquely
identified by an integer `identifier`.

Class `Buttons` models a collection of buttons, with the convention
that the `k`th button in an instance of `Buttons` is a `Button` with
`identifier == k`.

This usage of identifiers is also relied upon to map buttons to
physical buttons on the Nez-Oba PCB: a comment in
[keys.h](/src/board/keys.h) includes a simple diagram that illustrates
how the 15 clickable buttons on the Nez-Oba board are numbered.

Correspondingly, module `buttons` includes constant `NEZOBA_BUTTONS`,
which is an instance of `Buttons` with all buttons available on the
Nez-Oba board.

## Keys: module `keys`

A `Key` instance represents a possible logical output of a controller,
signaling to the game that a certain key has been pressed. Each key is
uniquely identified by an integer `identifier`, as well as by a unique
name `key`. 

Class `Keys` models a collection of keys. The order of keys in an
instance of `Keys` is immaterial since the keys can be indexed by
`identifier` or by name `key`.

Module `keys` also includes constant `STANDARD_KEYS`, which includes
all keys available on a standard gamepad. Currently, the Nez-Oba
board's software does not support left stick and right
joystick/thumbstick events, whereas all other keys should be
available.

Adding support for the joysticks should not be hard, given that the
Arduino gamepad libraries already support them.

## Combos: module `combos`

A `Combo` instance represents a certain combination of keys. At the
moment, there are two kinds of combos:

- A `Press` represents the pressing of a single key. The press may be
  *turboed* (the key is repeatedly pressed and depressed as long as
  the triggering button is pressed) or *held* (the key is held until
  the triggering button is pressed). Currently, the Nez-Oba controller
  board only supports turbo with frequency of 75 Herz, and does not
  support `hold` presses.
  
- An `And` represents several simultaneous `Press`es. Currently, the
  Nez-Oba controller board only supports up to three simultaneous
  presses.

## Mappings: module `mappings`

A `Mapping` instance represents a `Button` → `Combo` mapping. It is
built around Python dictionaries.

Class `Mappings` models a collection of mappings, all with the same
domain (an instance of `Buttons`) and with codomains with the same
keys used in `Combo`s (an instance of `Keys`).

Throughout this project, sometimes an instance of `Mappings` is also
referred to as a collection of *configurations*, where each
configuration corresponds to an instance of `Mapping`.

## Namings: module `namings`

Module `namings` provides wrappers around classes `Key`, `Keys`, and
`Mappings` that add associate platform-specific *names* to keys.

For example, the same gamepad key that is called `A` on a Nintendo Pro
Controller is called `B` on a PC/XBox controller.

Module `namings` also includes constant `NS_KEYS` and `PC_KEYS`, which
includes all `keys.STANDARD_KEYS` with their names on a Nintendo
Switch gamepad and on a PC/Raspberry Pi controller, respectively.

## Serialization: module `serialization`

Module `serialization` provides functions to serialize/deserialize an
instance of `Mappings` to/from a YAML file.

Functions `to_yaml` and `from_yaml` are the two main entry points for
using this module.

## Encoding and decoding: module `encoding`

Module `serialization` provides means to convert a `Mapping` to the
format used by the Nez-Oba board's software (that is, a C array
format). This conversion is called *encoding* and is provided by
`Encoder.encode`.

Class `Encoder` also provides the reverse conversion, from a C array
format back to an instance of `Mapping`, called *decoding* and
provided by `Encoder.decode`.

Finally, `Encoder.show` formats a `Mapping` instance as a string that
mimicks the controller board's actual physical layout and is human
readable.

The rest of the software does not use class `Encoder` directly but
through class `Exporter`, which handles encoding and decoding through
files.

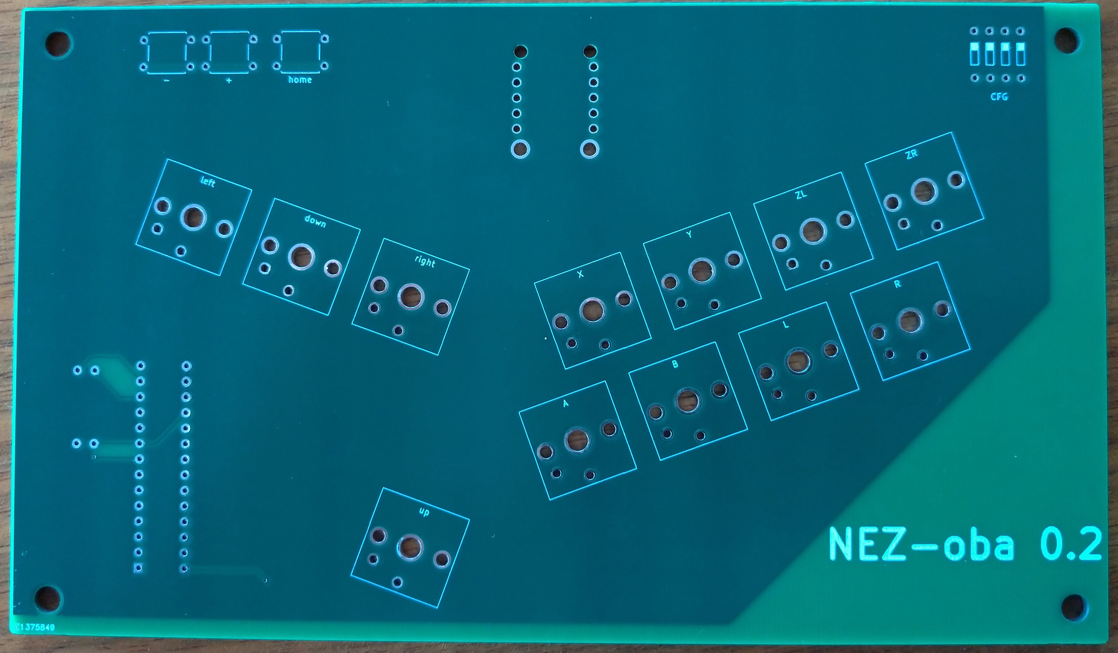
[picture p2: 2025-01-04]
hw/pics/PCB_front.jpg

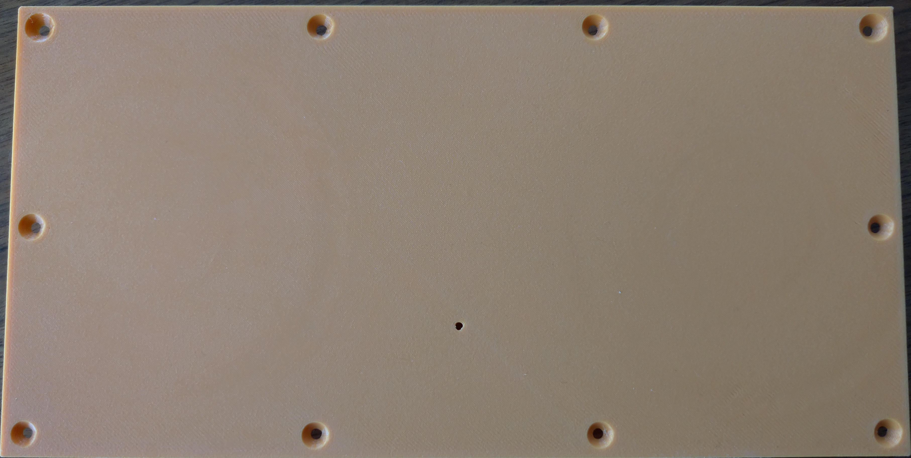
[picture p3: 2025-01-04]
hw/pics/case_orange_bottom_outside.jpg

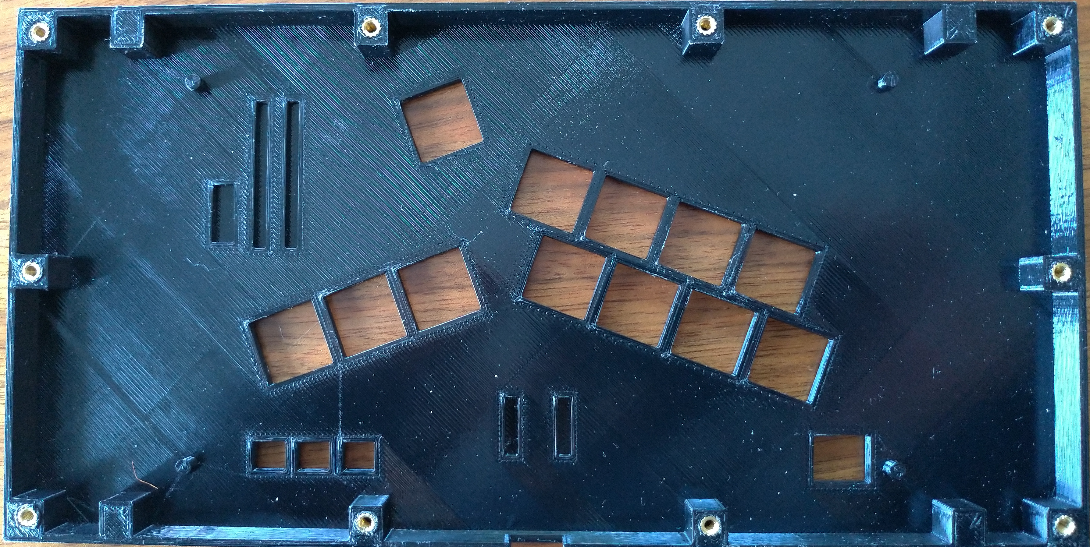
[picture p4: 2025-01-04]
hw/pics/case_black_top_inside.jpg

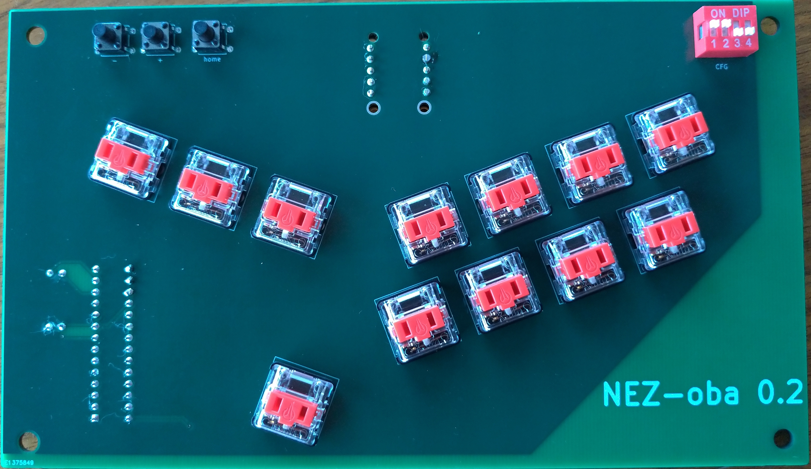
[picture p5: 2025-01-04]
hw/pics/board_front.jpg

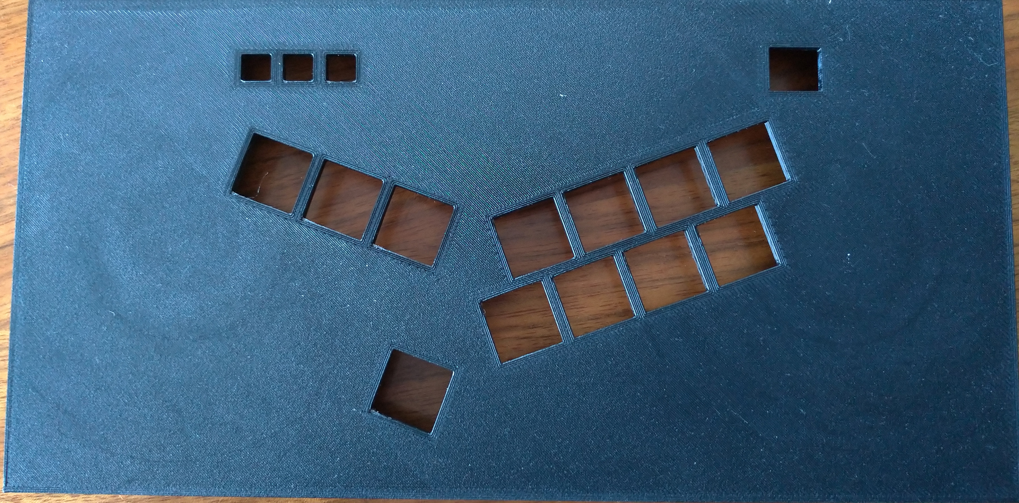
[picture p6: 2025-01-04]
hw/pics/case_black_top_outside.jpg

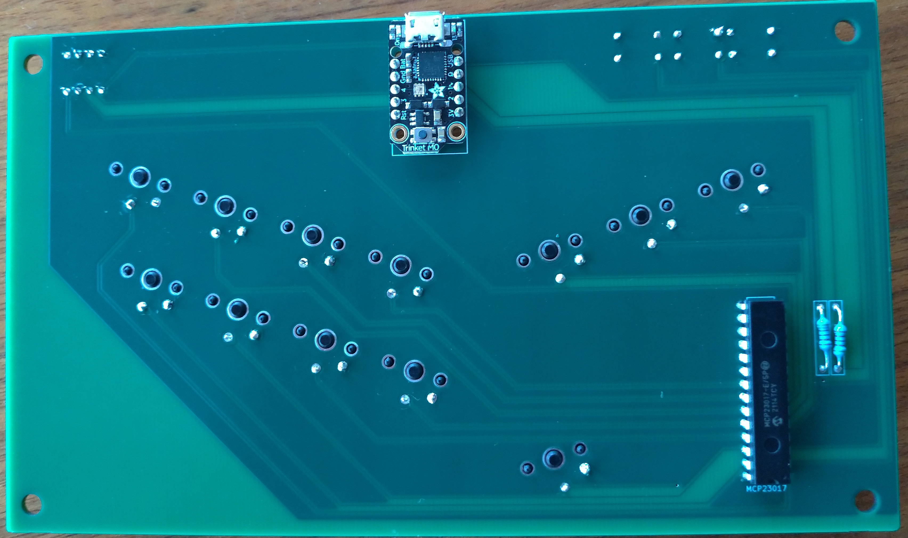
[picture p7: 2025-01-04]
hw/pics/board_back.jpg

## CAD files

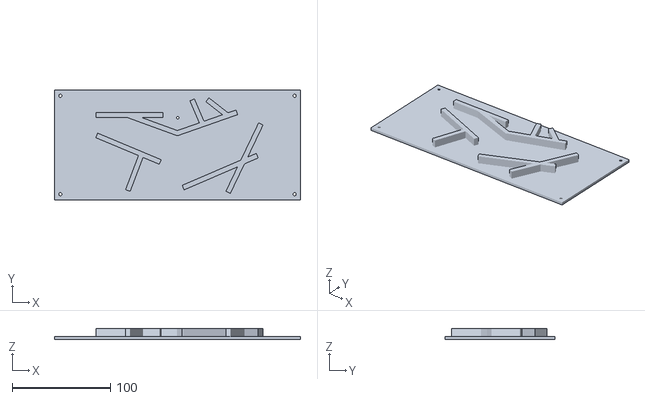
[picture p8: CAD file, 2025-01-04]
hw/case/case-bottom-wide.stl
250.0 x 112.0 x 11.2

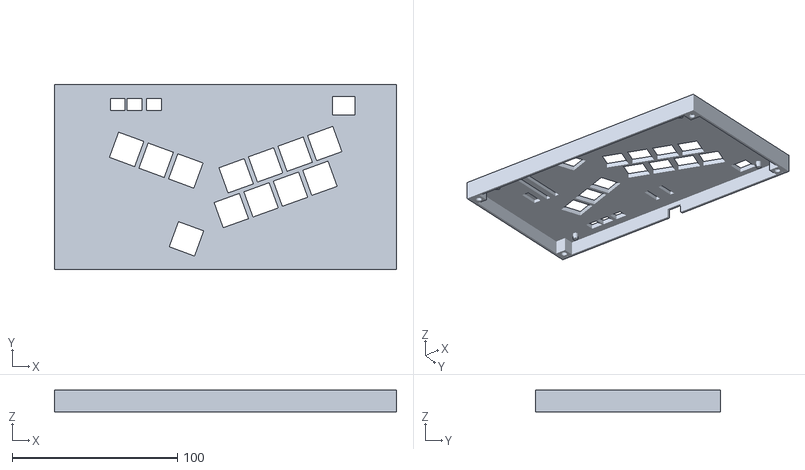
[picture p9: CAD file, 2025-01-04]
hw/case/case-top-narrow.stl
207.0 x 112.0 x 13.3

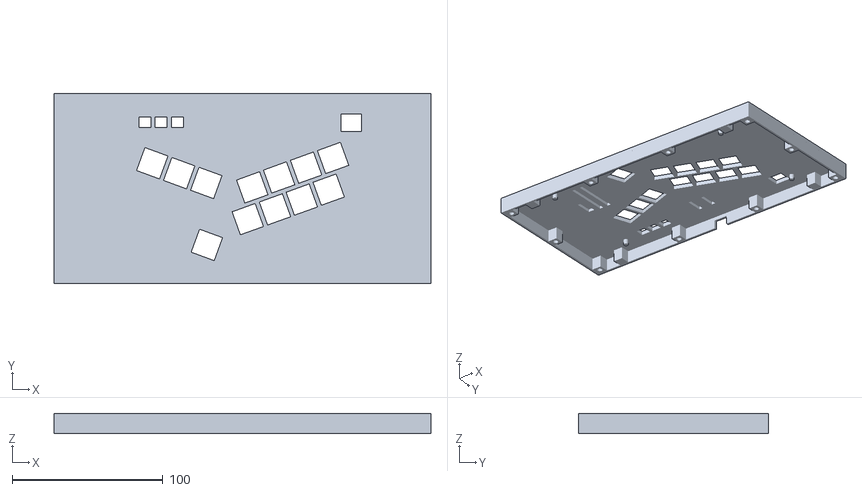
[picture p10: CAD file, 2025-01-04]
hw/case/case-top-2.stl
250.0 x 126.0 x 13.3

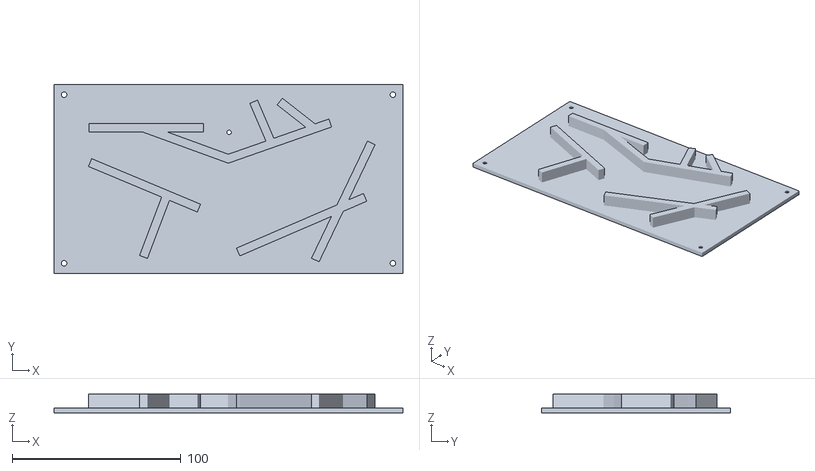
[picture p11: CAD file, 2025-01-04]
hw/case/case-bottom-narrow.stl
207.0 x 112.0 x 11.2

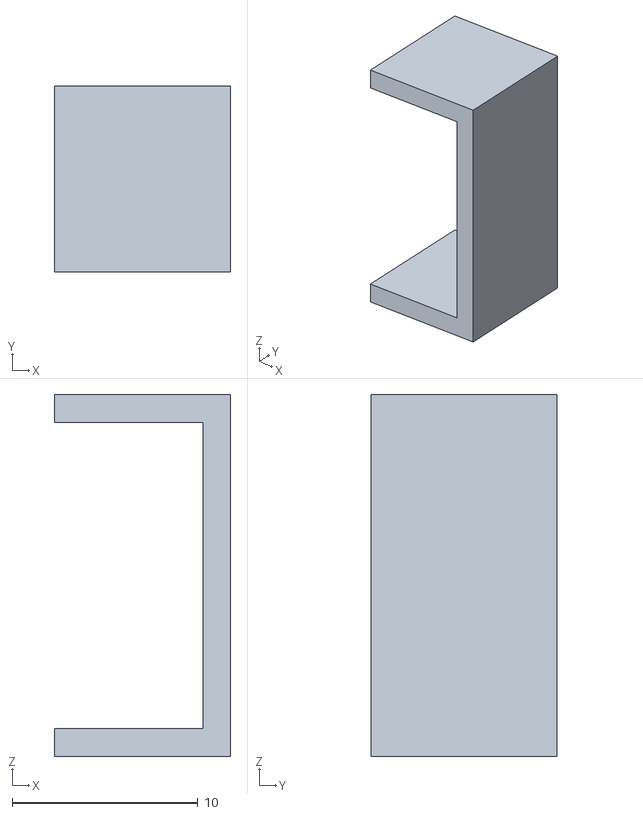
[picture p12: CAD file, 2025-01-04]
hw/case/clip.stl
9.50 x 10.0 x 19.5

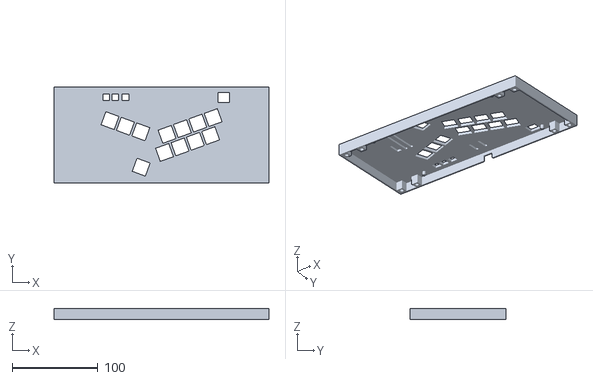
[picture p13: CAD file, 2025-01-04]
hw/case/case-top-wide.stl
250.0 x 112.0 x 13.3

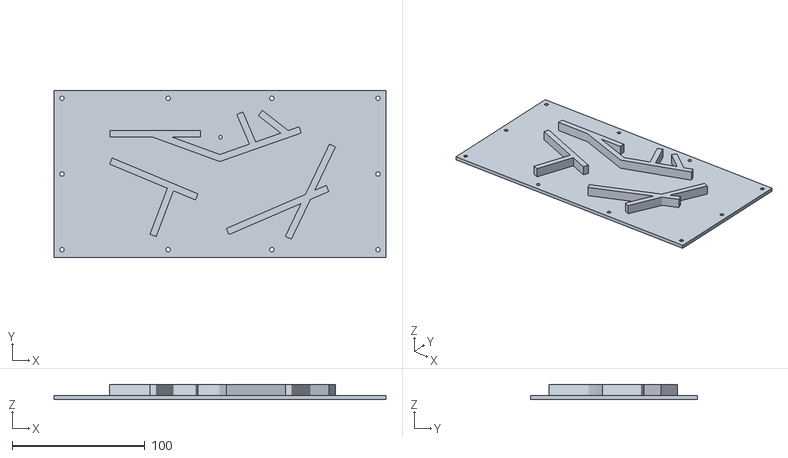
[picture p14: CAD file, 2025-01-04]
hw/case/case-bottom-2.stl
250.0 x 126.0 x 11.2

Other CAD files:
hw/case/case-2.blend
hw/case/case.blend

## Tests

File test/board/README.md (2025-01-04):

# Controller software offline testing

This directory contains several unit tests for the controller board's
software in [src/board/](/src/board/).

Before you test and deploy the controller's software on the board, you
may want to test that its logic and remapping work as expected. To
this end, this directory includes plain C++ stubs for the Arduino
libraries used by the controller, as well as a testing loop that
allows you to do some checks that there are no obvious crashes or
inconsistent usage of the data.

Compile and run the testing program as a standard C++ program:

```sh
make test  # equivalent to: g++ -o test test.cpp
./test
```

The testing program first executes the setup code once (in Arduino, 
function `setup()`). Before doing this, it prompts the user for up to
four *control bits*. These are the four bits read on the 4-bit switch
that determine which remapping is used. Type up to four `0`/`1` values
and then `Enter`; any values not provided on the command line (or
unrecognized) will be set to `0`.

```console
SETUP: reading control bits (up to 4 0/1 values)
0 0 1 foo [Enter]

[...]

Configuration number is: 2 (0 0 1 0)
```

Then, the testing program executes the main control loop body (in
Arduino, function `loop()`) repeatedly until it is terminated with
`Ctrl + C`. Before each iteration, it prompts the user for any number
of button presses, each identified by an integer. Any value that is
not recognized as an integer in the given range is ignored; repeating
the same integer several times is allowed (and equivalent to just
typing it once). After reading this input, the testing program acts as
if those buttons where pressed simultaneously, and shows the
corresponding presses that the controller would issue.

```console
CONTROL LOOP ITERATION #1: reading presses (integers in [0..14])
0 10 6 10 bar [Enter]

[...]

[Gamepad] Press button 16

[...]

[Gamepad] Press button 13

[...]

[Gamepad] Sets D-pad to direction 6
```

Each button press corresponds is first translated into (up to 3) key presses
according to the remapping in the current configuration.
Each key corresponds to a directional input or to a controller button.

   - In the first case, all directional inputs are recorded in the
     loop iteration, and at the end they are translated into a single
     8-way direction (up, up right, and so on). Contradicting
     direction results in a neutral directional inputs; for example,
     keys left and right cancel each other out.
	 
   - In the second case, the corresponding controller button is
     pressed.
	 
All controller inputs in one iteration are sent to the gamepad at the
end. All buttons that were not pressed are released on the gamepad.

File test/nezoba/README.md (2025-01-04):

# Python code testing

This directory contains several unit tests for the modules in
[src/nezoba/](/src/nezoba/). To run the tests, install
`pytest` and run:

```console
$ pytest
```

in the current directory.

This will run all tests; for selective testing, try these `pytest` options:

   - `pytest gui` only runs the tests for package `gui`.
	 
   - `pytest -k "parse"` only runs test methods whose name includes
     the string `parse`.
	 
   - `pytest -s` dumps standard output to terminal while the tests
     run. This is useful for debugging, to detect the effect of any
     `print` statement. Try it with tests `test_encoding`.

Due to some relative imports of auxiliary files, calling `pytest` from
a subdirectory of this directory may introduce spurious import
errors. Just call all the tests from this directory to avoid this
issue.

## Testing the interactive shell

File `test_shell.sh` sends a series of commands to the interactive
shell to test that it works correctly. Simply run the script from this
directory:

```
./test_shell.sh
```

This testing script creates and then deletes a temporary file.

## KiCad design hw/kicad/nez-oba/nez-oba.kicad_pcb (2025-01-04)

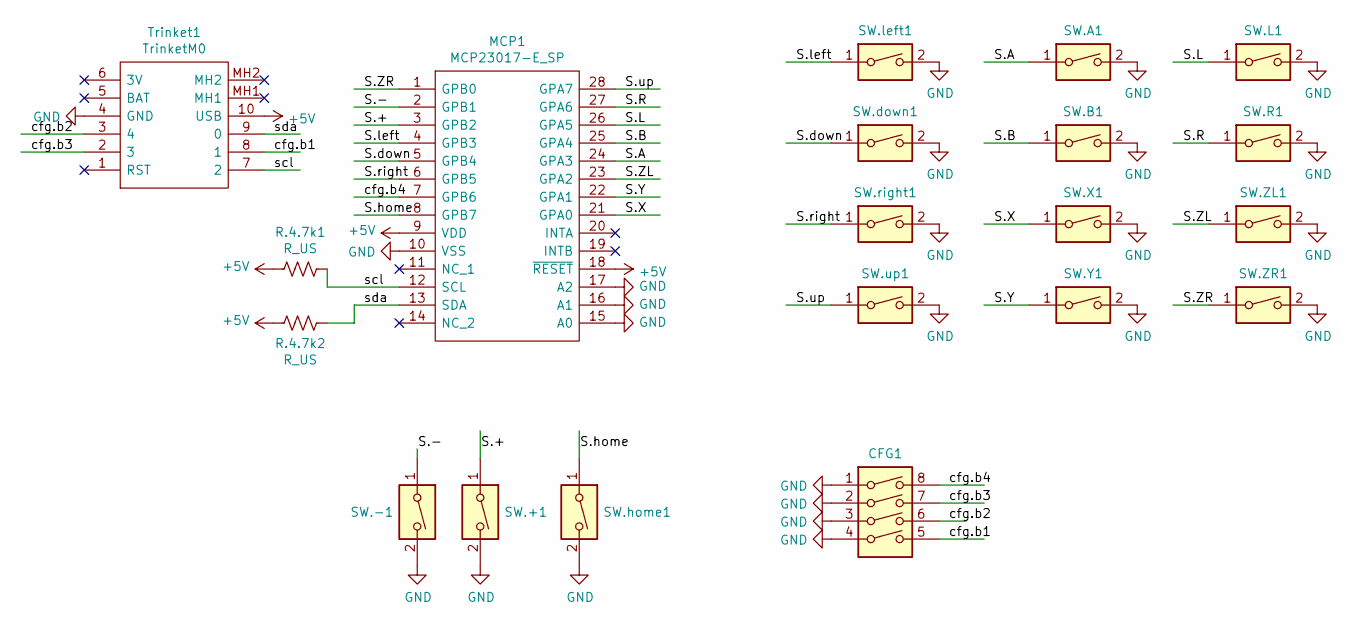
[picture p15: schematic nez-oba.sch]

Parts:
CFG1: SW_DIP_x04; SW_DIP_SPSTx04_Slide_6.7x11.72mm_W7.8mm_P2.54mm; Manufacturer_Part_Number KG04E; Digi-Key Part Number 2449-KG04E-ND
MCP1: MCP23017-E_SP; DIP-28_W7.62mm; Manufacturer_Part_Number MCP23017-E/SP; Digi-Key Part Number MCP23017-E/SP-ND
R.4.7k1, R.4.7k2: R_US; R_LDR_P12mm_narrow; Manufacturer_Part_Number ROX1SJ4K7; Digi-Key Part Number A131473CT-ND
SW.+1, SW.-1, SW.home1: SW_DIP_x01_tactile; SW_SPST_B3S-1000; Manufacturer_Part_Number 430476085716; Digi-Key Part Number 430476085716-ND
SW.A1, SW.B1, SW.L1, SW.R1, SW.X1, SW.Y1, SW.ZL1, SW.ZR1, SW.down1, SW.left1, SW.right1, SW.up1: SW_DIP_x01_Kailh_Choc_Red; Kailh_Choc_LowProfile_CPG135001D02; Manufacturer_Part_Number 5113; Digi-Key Part Number 1528-5113-ND
Trinket1: TrinketM0; Trinket_M0; Manufacturer_Part_Number 3500; Digi-Key Part Number 1528-2361-ND

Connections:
+5V: MCP1.9 (VDD), MCP1.18 (~RESET), R.4.7k1.2, R.4.7k2.2, Trinket1.10 (USB)
/S.+: MCP1.3 (GPB2), SW.+1.1
/S.-: MCP1.2 (GPB1), SW.-1.1
/S.A: MCP1.24 (GPA3), SW.A1.1
/S.B: MCP1.25 (GPA4), SW.B1.1
/S.L: MCP1.26 (GPA5), SW.L1.1
/S.R: MCP1.27 (GPA6), SW.R1.1
/S.X: MCP1.21 (GPA0), SW.X1.1
/S.Y: MCP1.22 (GPA1), SW.Y1.1
/S.ZL: MCP1.23 (GPA2), SW.ZL1.1
/S.ZR: MCP1.1 (GPB0), SW.ZR1.1
/S.down: MCP1.5 (GPB4), SW.down1.1
/S.home: MCP1.8 (GPB7), SW.home1.1
/S.left: MCP1.4 (GPB3), SW.left1.1
/S.right: MCP1.6 (GPB5), SW.right1.1
/S.up: MCP1.28 (GPA7), SW.up1.1
/cfg.b1: CFG1.5, Trinket1.8 (1~)
/cfg.b2: CFG1.6, Trinket1.3 (4)
/cfg.b3: CFG1.7, Trinket1.2 (3)
/cfg.b4: CFG1.8, MCP1.7 (GPB6)
/scl: MCP1.12 (SCL), R.4.7k1.1, Trinket1.7 (2)
/sda: MCP1.13 (SDA), R.4.7k2.1, Trinket1.9 (0)
GND: CFG1.1, CFG1.2, CFG1.3, CFG1.4, MCP1.10 (VSS), MCP1.15 (A0), MCP1.16 (A1), MCP1.17 (A2), SW.+1.2, SW.-1.2, SW.A1.2, SW.B1.2, SW.L1.2, SW.R1.2, SW.X1.2, SW.Y1.2, SW.ZL1.2, SW.ZR1.2, SW.down1.2, SW.home1.2, SW.left1.2, SW.right1.2, SW.up1.2, Trinket1.4 (GND)

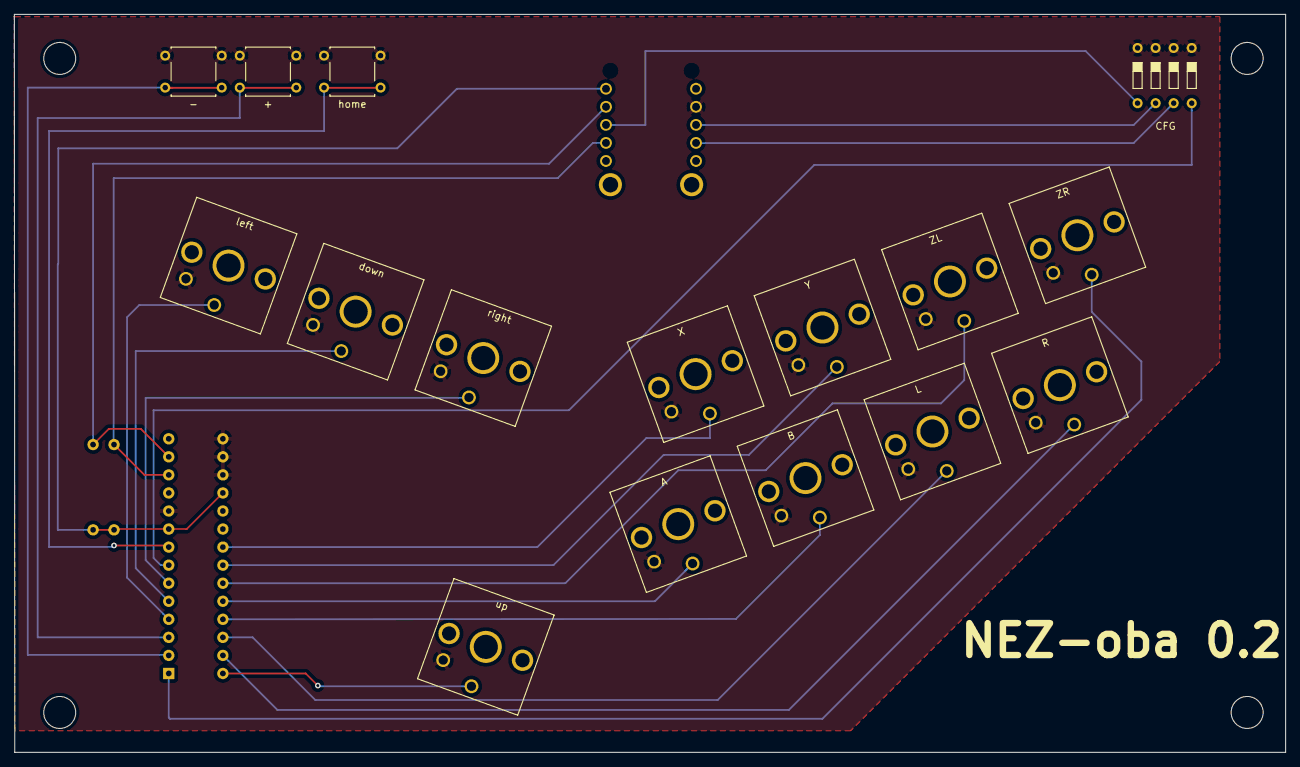
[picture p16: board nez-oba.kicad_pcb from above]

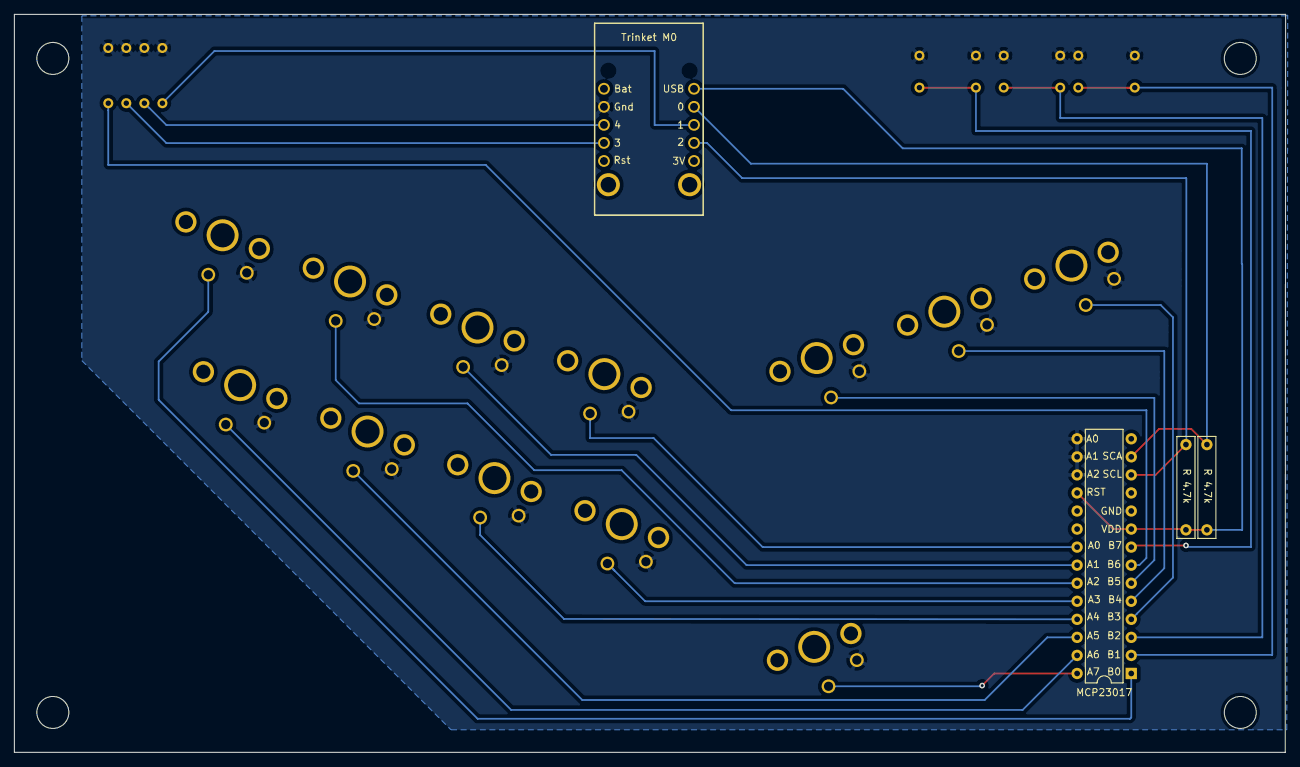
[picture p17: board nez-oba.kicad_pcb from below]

Board: 2 copper layers, 178.9 x 103.8 mm, 20 parts (4 on the bottom side), 23 nets.

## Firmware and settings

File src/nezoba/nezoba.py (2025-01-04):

"""Main entry point for the Nez-Oba controller board software."""

import argparse
import logging
from enum import Enum
from typing import Optional
from importlib import resources as impresources
import os
import tempfile

import board as nezoba_board
import data as nezoba_data
from .shell import cli_shell
from .remapper.encoding import Exporter
from .deployer import Installer, Deployer

_default_yaml = impresources.files(nezoba_data) / "platformers-2d.yaml"
_default_project_dir = impresources.files(nezoba_board) / ""

class Command(Enum):
    """Available commands."""
    SHOW = "show"
    GUI = "gui"
    CLI = "cli"
    SETUP = "setup"
    DEPLOY = "deploy"
    IMPORT = "import"


_DESCRIPTION = """
This script is the entry point to configuring the Nez-Oba controller
board for use. It provides a simple command-line interface to:

- show: show the content of a button-to-key-presses YAML mapping file.
- gui: edit the content of a button-to-key-presses YAML mapping file
  with a GUI.
- gui: edit the content of a button-to-key-presses YAML mapping file
  with a minimal CLI shell.
- setup: install the Arduino compiler and libraries needed to build
  the Nez-Oba board's software.
- deploy: compile and deploy a chosen series of button-to-key-presses
  mappings to the board.
- import: translate a deployed button-to-key-presses mappings back to
  a YAML mapping file for further editing.
"""


def cmd_parser() -> argparse.ArgumentParser:
    """Create the command-line parser."""
    parser = argparse.ArgumentParser(
        description=_DESCRIPTION,
        formatter_class=lambda prog: argparse.RawTextHelpFormatter(prog, width=35)
    )

    parser.add_argument("--debug", default=False, action="store_true",
                        help="print debugging information")
    parser.add_argument("--log", nargs=None,
                        help="write debugging information to this file")

    subparsers = parser.add_subparsers(dest="command", required=True,
                                       help="command to execute")
    cmd_parsers = {
        Command.SHOW:
        subparsers.add_parser(
            "show",
            help="print the content of a button-to-key-presses YAML mapping file"
        ),
        Command.GUI:
        subparsers.add_parser(
            "gui",
            help="start the GUI to edit a button-to-key-presses YAML mapping file"
        ),
        Command.CLI:
        subparsers.add_parser(
            "cli",
            help="run the CLI shell to edit a button-to-key-presses YAML mapping file"
        ),
        Command.SETUP:
        subparsers.add_parser(
            "setup",
            help="install the Arduino compiler and libraries needed by the Nez-Oba board"
        ),
        Command.DEPLOY:
        subparsers.add_parser(
            "deploy",
            help="compile and deploy to the board a button-to-key-presses YAML mapping file"
        ),
        Command.IMPORT:
        subparsers.add_parser(
            "import",
            help="translate a deployed button-to-key-presses mappings back to a YAML mapping file"
        )
    }

    cmd_parsers[Command.SHOW].add_argument(
        "mappings",
        help="path to the YAML mappings file (default: %(default)s)",
        default=_default_yaml,
        nargs="?"
        )

    cmd_parsers[Command.GUI].add_argument(
        "mappings",
        help="path to the YAML mappings file (default: empty mappings)",
        nargs="?"
        )

    cmd_parsers[Command.CLI].add_argument(
        "mappings",
        help="path to the YAML mappings file to create or modify"
        )

    cmd_parsers[Command.SETUP].add_argument(
        "system_dir",
        help="path where to install the Arduino compiler and libraries"
        )
    cmd_parsers[Command.SETUP].add_argument(
        "--overwrite", default=False, action="store_true",
        help="if the project directory already exists, delete it first"
        )
    cmd_parsers[Command.SETUP].add_argument(
        "--batch", default=False, action="store_true",
        help="do not wait for user confirmation before running each command"
        )

    cmd_parsers[Command.DEPLOY].add_argument(
        "mappings",
        help="path to the YAML mappings file (default: %(default)s)",
        default=_default_yaml,
        nargs="?"
        )
    cmd_parsers[Command.DEPLOY].add_argument(
        "nezoba_sw",
        help="path to the Nez-Oba board's software directory (default: %(default)s)",
        default=_default_project_dir,
        nargs="?"
        )
    cmd_parsers[Command.DEPLOY].add_argument("arduino",
                                             help="path to an installation of the Arduino CLI")
    cmd_parsers[Command.DEPLOY].add_argument(
        "--port", default=None,
        help="use the given serial port to upload to the board (default: try all available ports)"
        )
    cmd_parsers[Command.DEPLOY].add_argument(
        "--batch", default=False, action="store_true",
        help="do not wait for user confirmation before running each command"
        )
    cmd_parsers[Command.DEPLOY].add_argument(
        "--overwrite", default=False, action="store_true",
        help=("if mappings are already present in the project directory, overwrite them "
              "(default: keep the old mappings as backup)")
        )

    cmd_parsers[Command.IMPORT].add_argument(
        "mappings",
        help="path to the YAML mappings file that will be created"
        )
    cmd_parsers[Command.IMPORT].add_argument(
        "nezoba_sw",
        help=("path to the Nez-Oba board's software directory, "
              "where the deployed mappings are stored (default: %(default)s)"),
        default=_default_project_dir,
        nargs="?"
        )
    cmd_parsers[Command.IMPORT].add_argument(
        "--overwrite", default=False, action="store_true",
        help=("if a YAML mappings file at that path is already present, overwrite it "
              "(default: keep the old mappings file as a backup)")
        )

    return parser


def setup_logging(enable: bool = True, log_file: Optional[str] = None):
    """Enable/disable displaying logging information."""
    # handle warnings with the logging module
    logging.captureWarnings(True)
    # Create JustPy environment file
    justpy_env_dir = tempfile.mkdtemp(prefix="justpy_config")
    justpy_env_path = os.path.join(justpy_env_dir, "justpy.env")
    justpy_env_file = open(justpy_env_path, "w", encoding="utf-8")
    os.environ["JUSTPY_ENV_FILE"] = justpy_env_file.name
    logger = logging.getLogger()
    justpy_logger = logging.getLogger("justpy")
    if enable:
        logger.setLevel(logging.INFO)
        justpy_logger.setLevel(logging.INFO)
        justpy_env_file.write("DEBUG=True\nVERBOSE=True\n")
    else:
        logger.setLevel(logging.CRITICAL)
        justpy_logger.setLevel(logging.CRITICAL)
        justpy_env_file.write("DEBUG=False\nVERBOSE=False\n")
    logging.info("JustPy configuration file: %s", justpy_env_path)
    justpy_env_file.close()
    while logger.hasHandlers():
        logger.removeHandler(logger.handlers[0])
    while justpy_logger.hasHandlers():
        justpy_logger.removeHandler(justpy_logger.handlers[0])
    if log_file:
        # log to file
        handler = logging.FileHandler(log_file, mode="w")
    else:
        # log to console
        handler = logging.StreamHandler()
    formatter = logging.Formatter("%(pathname)s - line %(lineno)s - %(levelname)s - %(message)s")
    handler.setFormatter(formatter)
    logger.addHandler(handler)
    justpy_logger.addHandler(handler)

def show(mapping_yaml: str):
    """Show the content of a button-to-key-presses mapping file."""
    exporter = Exporter("", mapping_yaml)
    print(exporter.show())

def gui(mapping_yaml: Optional[str]):
    """Launch the GUI (opening the given button-to-key-presses mapping file if given)."""
    # pylint: disable=import-outside-toplevel # To properly configure justpy's output, I need to import here
    import justpy
    from .gui.gui import nezoba_gui
    justpy.justpy(lambda: nezoba_gui(mapping_yaml))

def encode(mapping_yaml: str, project_dir: str, bak: bool):
    """Encode a button-to-key-presses mapping file to C header files in `project_dir`."""
    exporter = Exporter(project_dir, mapping_yaml)
    exporter.encode(bak=bak)

def decode(mapping_yaml: str, project_dir: str, bak: bool):
    """Decode a button-to-key-presses mapping file from C header files in `project_dir`."""
    importer = Exporter(project_dir, mapping_yaml)
    importer.decode(bak=bak)


def main(args: argparse.Namespace=None):
    """Parse and process commands."""
    if args is None:
        parser = cmd_parser()
        args = parser.parse_args()
    setup_logging(args.debug, args.log)
    if args.command == Command.SHOW.value:
        show(args.mappings)
    elif args.command == Command.GUI.value:
        gui(args.mappings)
    elif args.command == Command.CLI.value:
        cli_shell(args.mappings)
    elif args.command == Command.SETUP.value:
        installer = Installer(args.system_dir, args.overwrite, not args.batch)
        installer.setup()
    elif args.command == Command.DEPLOY.value:
        encode(args.mappings, args.nezoba_sw, not args.overwrite)
        deployer = Deployer(args.arduino, args.nezoba_sw,
                            args.port, not args.batch)
        deployer.deploy()
    elif args.command == Command.IMPORT.value:
        decode(args.mappings, args.nezoba_sw, not args.overwrite)


if __name__ == "__main__":
    main()

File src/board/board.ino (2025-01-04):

/* NOTE: This .ino file must have the same filename as the containing project directory */
// comment out to disable debug output
// #define DEBUG

#include "debug.h"

#include "keys.h"
#include "mcp.h"
#include "globals.h"



void setup() {

#include "setup.h"
  
}



#include "key_handler.h"


void loop() {

#include "main_loop.h"

}
